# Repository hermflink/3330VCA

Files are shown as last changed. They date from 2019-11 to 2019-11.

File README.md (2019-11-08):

# 3330VCA

Kicad project files of a AS3330 based dual VCA. Part of a modular DIY synth project, other modules are available in other repositories. Not entirely compatible with a CEM3330 as this would require a diode to ground on pin 4.

Used the Audio.lib from https://kicad.github.io/symbols/Audio to extend the Kicad library for the AS3330 component.

Designed to work with +/- 15V, not tested for +/- 12V

The PCB is 9.5 x 5.5 cm and has no PCB-mounting of potmeters, switches, jacks; these are all connected by pin header connectors

The PCB  has a fault: the connection between pin 5 and 8 of AS3330 on the backplane should be removed. Instead, pin 5 should be connected to R15/R17 as the schema points out.

Loosely based on http://www.digisound80.co.uk/digisound/modules/80-9_files/80-9_ETI.pdf

R4, C2, R18 and C8 can be safely left out.

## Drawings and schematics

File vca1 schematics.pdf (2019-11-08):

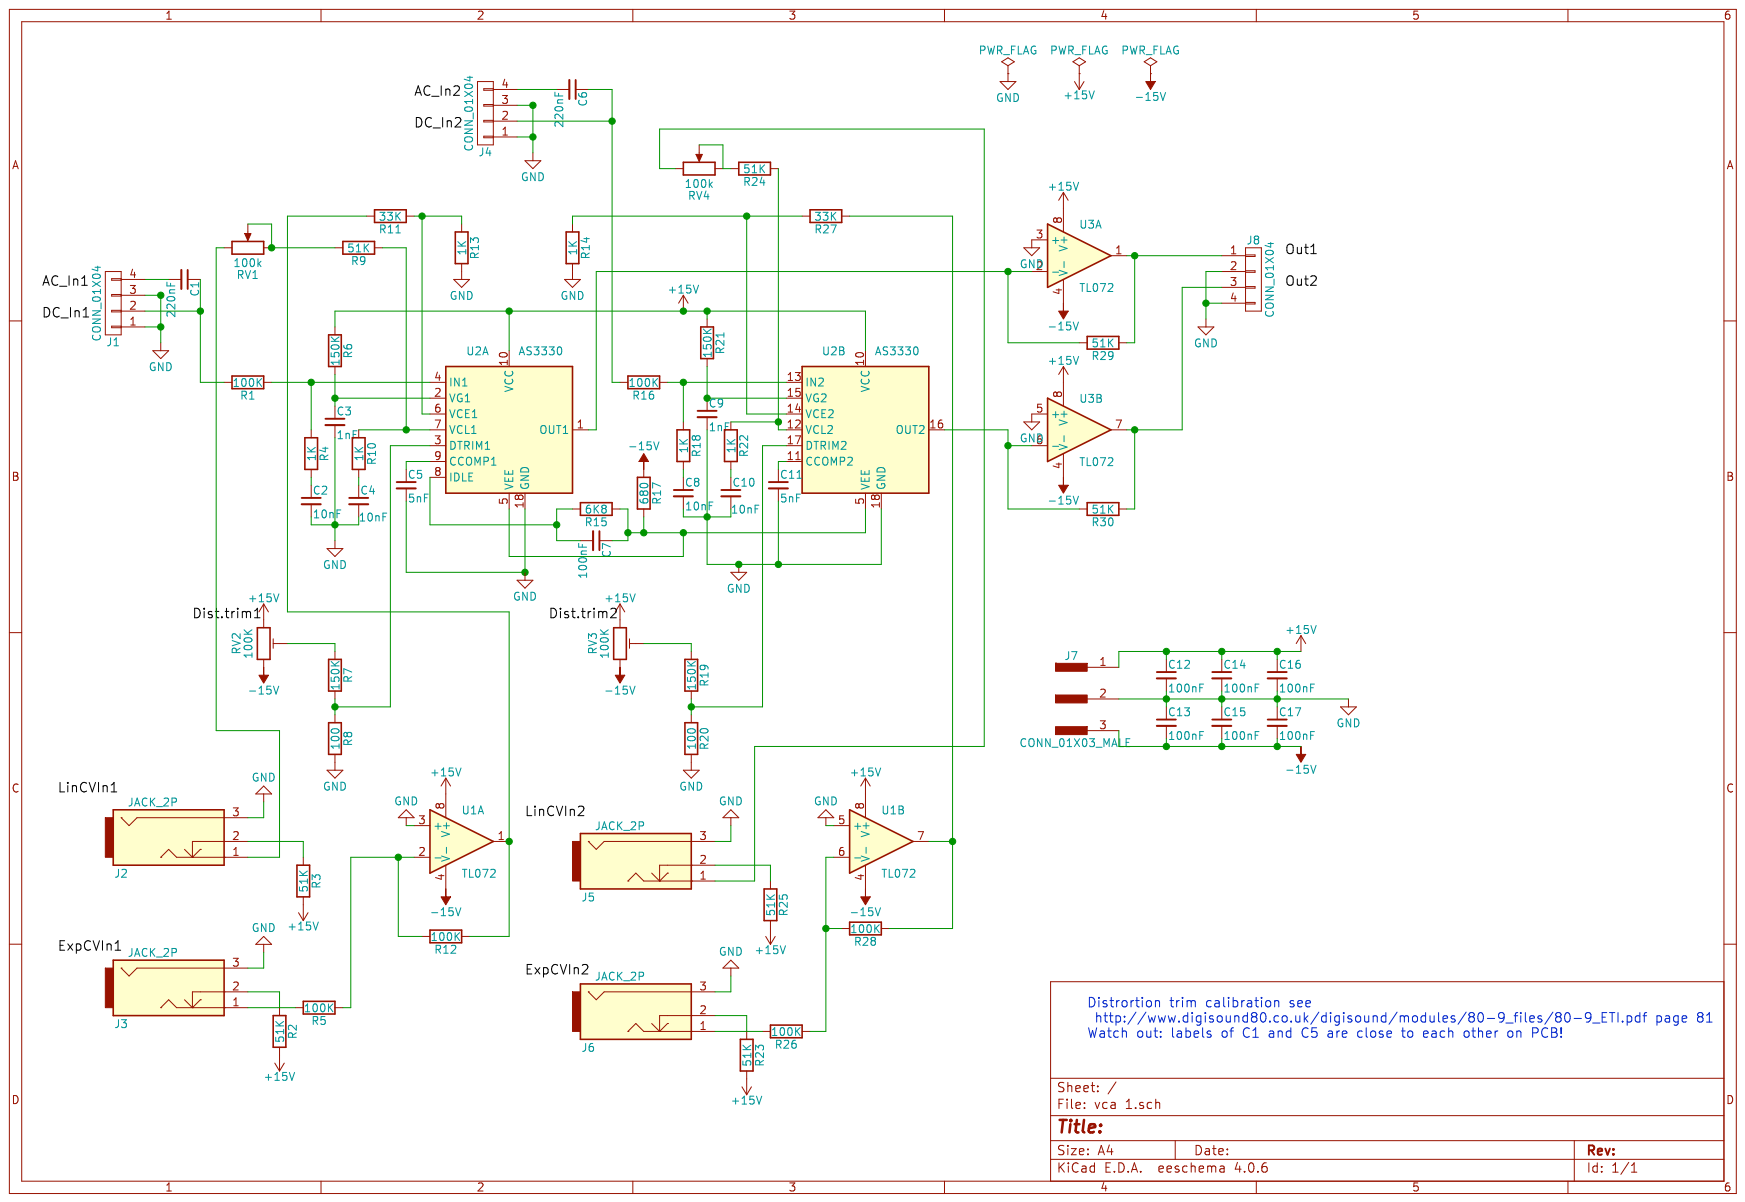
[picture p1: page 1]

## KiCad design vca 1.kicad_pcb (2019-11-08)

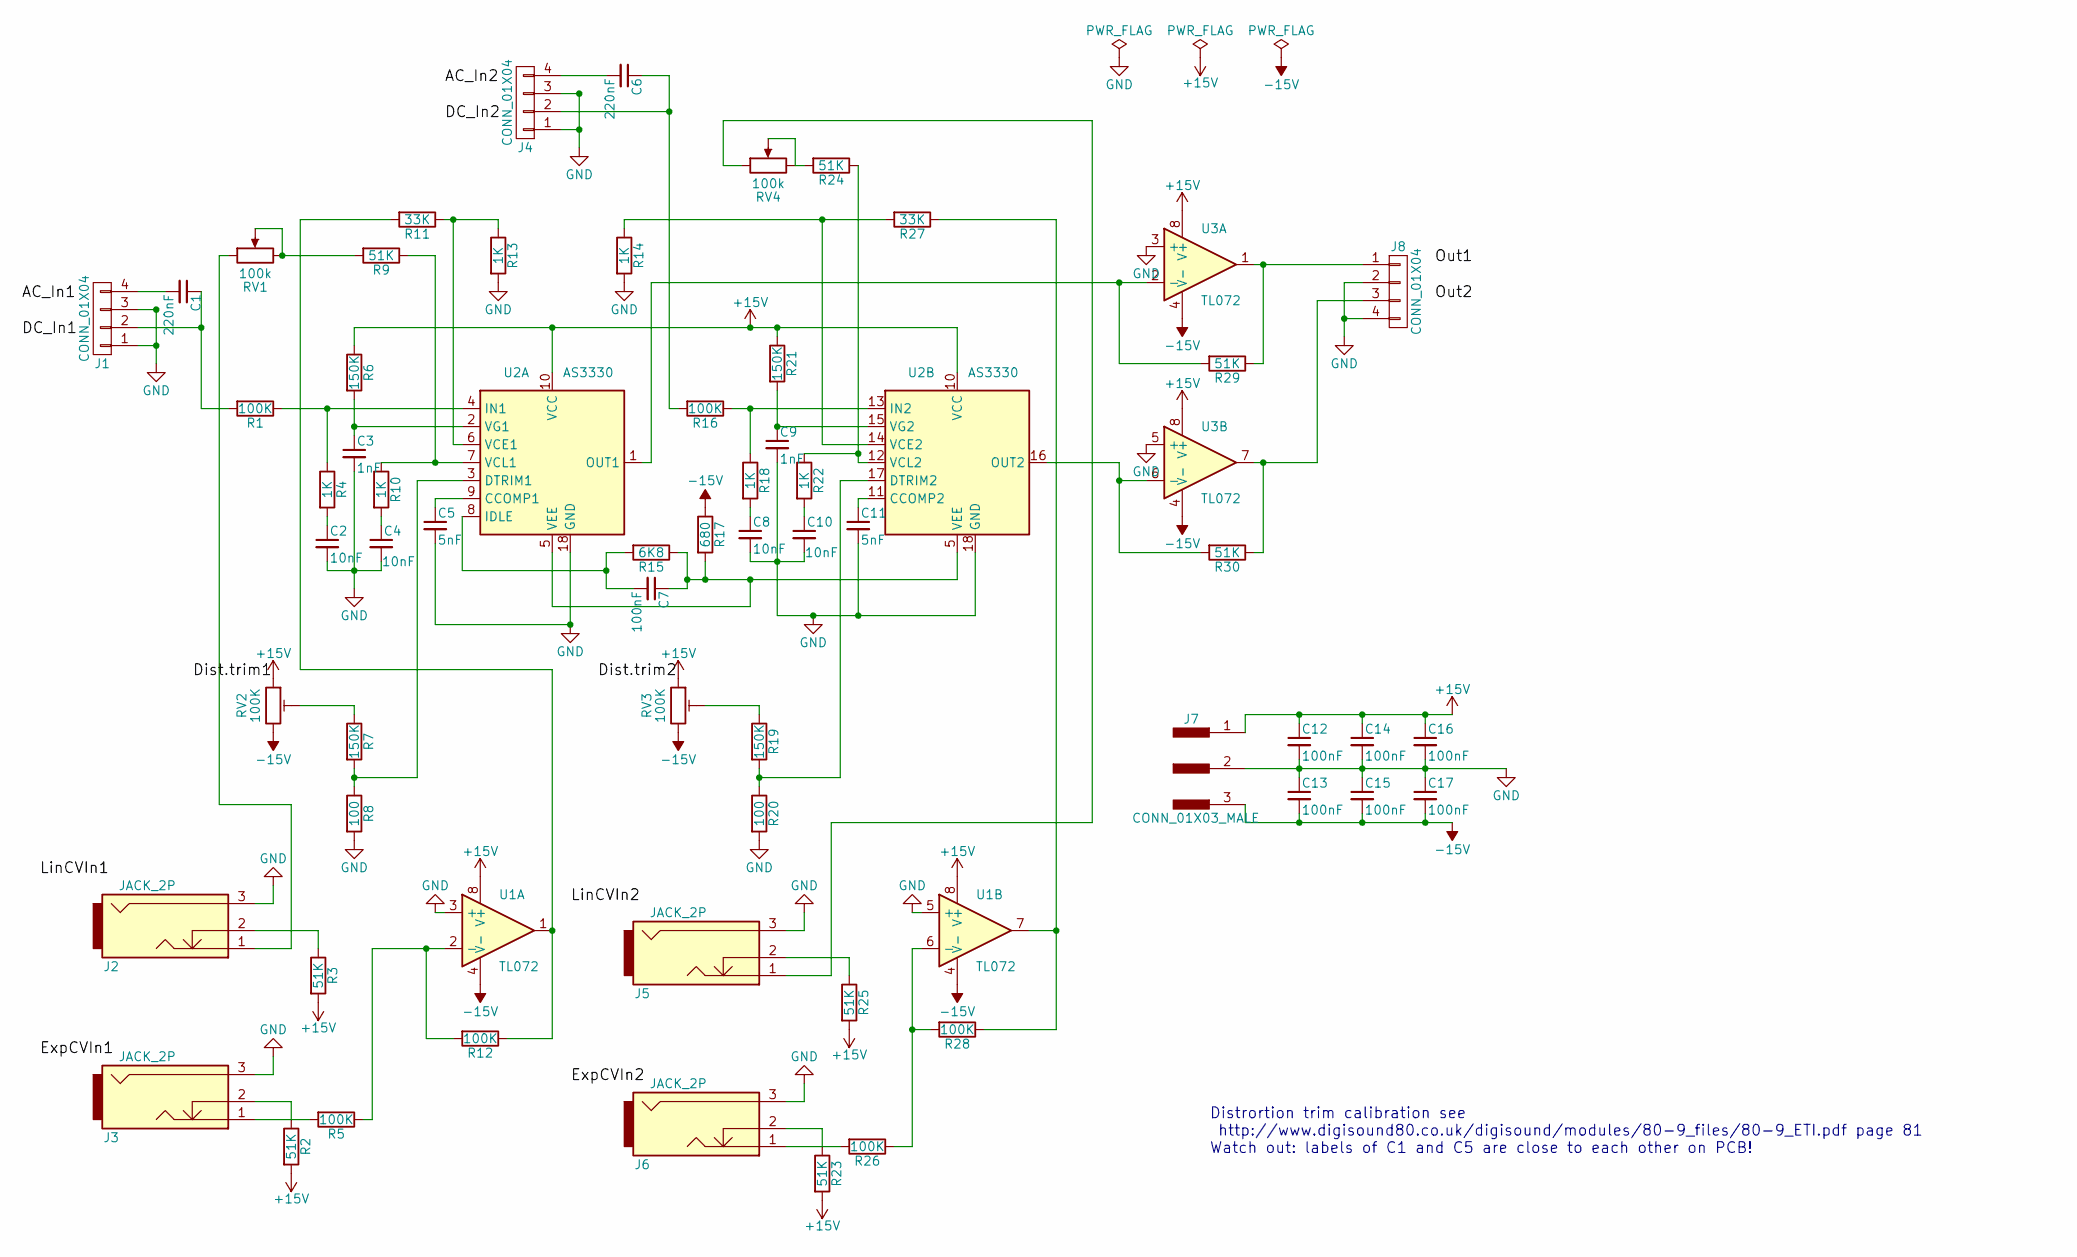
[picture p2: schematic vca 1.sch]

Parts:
C1, C6: 220nF; C_Disc_D5.0mm_W2.5mm_P5.00mm
C2, C4, C8, C10: 10nF; C_Disc_D5.0mm_W2.5mm_P5.00mm
C3, C9: 1nF; C_Disc_D5.0mm_W2.5mm_P5.00mm
C5, C11: 5nF; C_Disc_D5.0mm_W2.5mm_P5.00mm
C7, C12, C13, C14, C15, C16, C17: 100nF; C_Disc_D5.0mm_W2.5mm_P5.00mm
J1, J4, J8: CONN_01X04; Pin_Header_Straight_1x04_Pitch2.54mm
J2, J3, J5, J6: JACK_2P; Pin_Header_Straight_1x03_Pitch2.54mm
J7: CONN_01X03_MALE; Pin_Header_Straight_1x03_Pitch2.54mm
R1, R5, R12, R16, R26, R28: 100K; R_Axial_DIN0207_L6.3mm_D2.5mm_P2.54mm_Vertical
R2, R3, R9, R23, R24, R25, R29, R30: 51K; R_Axial_DIN0207_L6.3mm_D2.5mm_P2.54mm_Vertical
R4, R10, R13, R14, R18, R22: 1K; R_Axial_DIN0207_L6.3mm_D2.5mm_P2.54mm_Vertical
R6, R7, R19, R21: 150K; R_Axial_DIN0207_L6.3mm_D2.5mm_P2.54mm_Vertical
R8, R20: 100; R_Axial_DIN0207_L6.3mm_D2.5mm_P2.54mm_Vertical
R11, R27: 33K; R_Axial_DIN0207_L6.3mm_D2.5mm_P2.54mm_Vertical
R15: 6K8; R_Axial_DIN0207_L6.3mm_D2.5mm_P2.54mm_Vertical
R17: 680; R_Axial_DIN0207_L6.3mm_D2.5mm_P2.54mm_Vertical
RV1, RV4: 100k; Pin_Header_Straight_1x03_Pitch2.54mm
RV2, RV3: 100K; Potentiometer_Trimmer_Bourns_3296W
U1, U3: TL072; DIP-8_W7.62mm_Socket_LongPads
U2: AS3330; DIP-18_W7.62mm_Socket_LongPads

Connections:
+15V: C12.1, C14.1, C16.1, J7.1, R2.2, R3.2, R6.1, R21.1, R23.2, R25.2, RV2.1, RV3.1, U1.8 (V+), U2.10 (VCC), U3.8 (V+)
-15V: C13.2, C15.2, C17.2, J7.3, R17.1, RV2.3, RV3.3, U1.4 (V-), U3.4 (V-)
GND: C2.2, C3.2, C4.2, C5.2, C8.2, C9.2, C10.2, C11.2, C12.2, C13.1, C14.2, C15.1, C16.2, C17.1, J1.1, J1.3, J2.3, J3.3, J4.1, J4.3, J5.3, J6.3, J7.2, J8.2, J8.4, R8.2, R13.2, R14.2, R20.2, U1.3 (+), U1.5 (+), U2.18 (GND), U3.3 (+), U3.5 (+)
unnamed: C1.1, J1.2, R1.2
unnamed: C1.2, J1.4
unnamed: C2.1, R4.2
unnamed: C3.1, R6.2, U2.2 (VG1)
unnamed: C4.1, R10.2
unnamed: C5.1, U2.9 (CCOMP1)
unnamed: C6.1, J4.2, R16.2
unnamed: C6.2, J4.4
unnamed: C8.1, R18.2
unnamed: C9.1, R21.2, U2.15 (VG2)
unnamed: C10.1, R22.2
unnamed: C11.1, U2.11 (CCOMP2)
unnamed: J2.1, RV1.1
unnamed: J2.2, R3.1
unnamed: J3.1, R5.2
unnamed: J3.2, R2.1
unnamed: J5.1, RV4.1
unnamed: J5.2, R25.1
unnamed: J6.1, R26.2
unnamed: J6.2, R23.1
unnamed: J8.1, R29.1, U3.1
unnamed: J8.3, R30.1, U3.7
unnamed: R1.1, R4.1, U2.4 (IN1)
unnamed: R7.1, RV2.2
unnamed: R7.2, R8.1, U2.3 (DTRIM1)
unnamed: R9.2, RV1.2, RV1.3
unnamed: R9.1, R10.1, U2.7 (VCL1)
unnamed: R11.1, R13.1, U2.6 (VCE1)
unnamed: R11.2, R12.1, U1.1
unnamed: R5.1, R12.2, U1.2 (-)
unnamed: R14.1, R27.2, U2.14 (VCE2)
unnamed: R16.1, R18.1, U2.13 (IN2)
unnamed: R19.1, RV3.2
unnamed: R19.2, R20.1, U2.17 (DTRIM2)
unnamed: R22.1, R24.1, U2.12 (VCL2)
unnamed: R24.2, RV4.2, RV4.3
unnamed: R26.1, R28.2, U1.6 (-)
unnamed: R27.1, R28.1, U1.7
unnamed: R29.2, U2.1 (OUT1), U3.2 (-)
unnamed: R30.2, U2.16 (OUT2), U3.6 (-)

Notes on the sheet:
Distrortion trim calibration see http://www.digisound80.co.uk/digisound/modules/80-9_files/80-9_ETI.pdf page 81 Watch out: labels of C1 and C5 are close to each other on PCB!

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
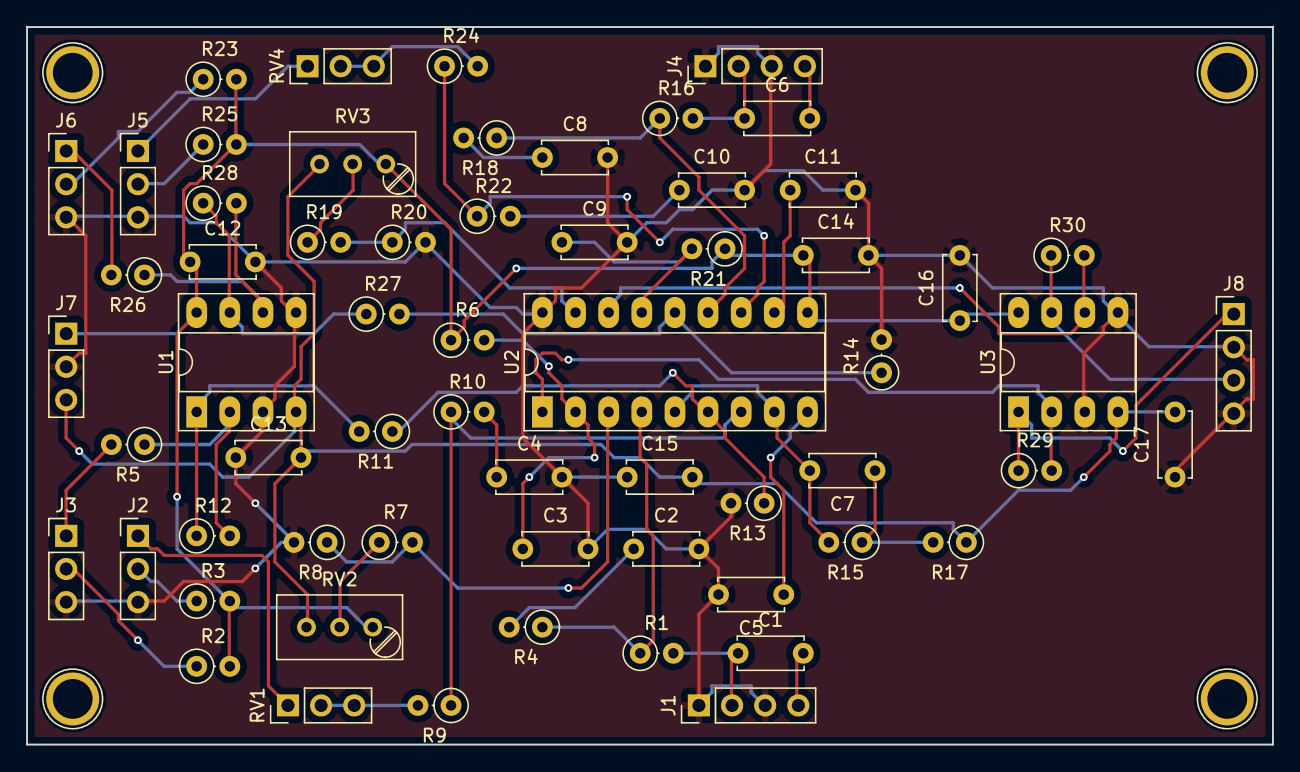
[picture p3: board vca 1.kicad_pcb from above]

Board: 2 copper layers, 95.5 x 55.0 mm, 62 parts (0 on the bottom side), 45 nets.
